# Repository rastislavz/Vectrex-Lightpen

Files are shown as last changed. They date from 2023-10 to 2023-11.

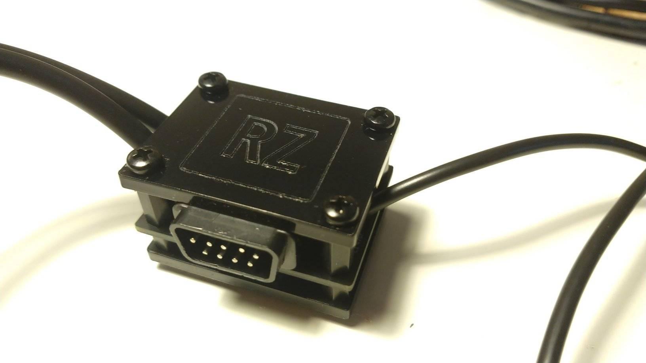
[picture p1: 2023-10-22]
Images/Lightpen2.jpg

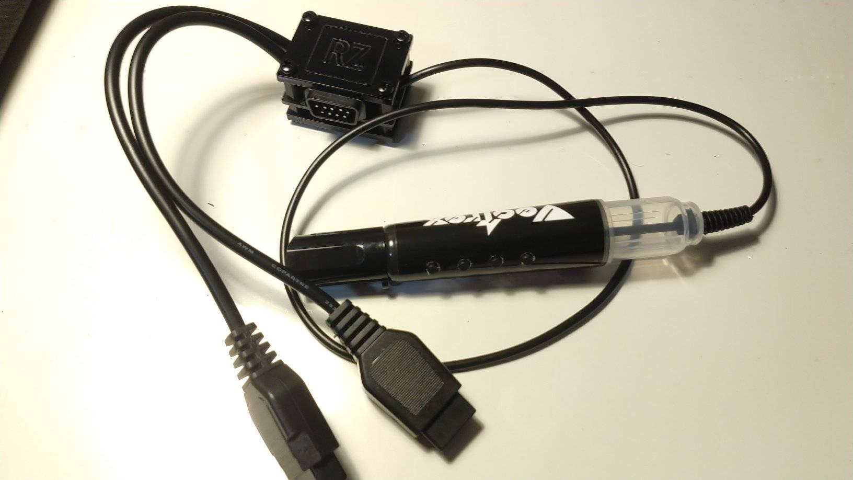
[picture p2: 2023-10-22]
Images/Lightpen1.jpg

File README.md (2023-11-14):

# Vectrex lightpen with integrated buttons

Lightpen1

# The construction details

The building of this lightpen is a bit tedious process since it uses the refillable whiteboard marker (PILOT V-Board Master 5979) instead some genuine build body.
The first step is to disembowel the marker guts: after the back is screwed open and the ink cartridge is taken out, the rest of the guts can be simply pulled out with the long nose pliers.
The next step is drilling the holes for cable and for 4 microswitch buttons. To drill the button holes precisely, i found the best way is to first apply the label with the precut button holes and to drill the holes after the label is applied. Since I had lots of labels made for the ordinary lightpen without precut holes, I have made the drill template (in svg directory) which I have printed out, overlaid with the label and than punched the holes with the leather holes puncher.

The cables are directly soldered into the PCBs. Both PCBs are designed with the holes for the cables which serves as strain relife when cables are threaded through the holes. The main body (or call it the lightpen box) PCB contains also smaller holes by which cables can be additionaly secured by cable ties.

The PCB with the microswitches and phototransistor has to be secure inside the pen with some piece of plastic/thick paper and glue.

Its quite interesting where I have found the plastic 9pin connector with 90° pins I have used in building the pen: when I needed 9pin cables for some Vectrex controllers I have used Sega etension cables and I have cut off the male part, and some of those had a small bump on it (like the one sold by console5 https://console5.com/store/atari-sega-commodore-6-1-8m-joystick-controller-extension-cable-cord.html). I was curious why that bump is there and when I have cracked it open, I have found out that Chinese have used the 90° PCB connectors for making the cable and they have just soldered wires onto the pins, but then they had to make that bump to fit. So you do not have to buy that connector if you are using the same cables for the build.

The box case is made with 2 laser cut acrilic (or whatewer material) sheet: in the svg folder.

Shield: [][cc-by-sa]

This work is licensed under a
[Creative Commons Attribution-ShareAlike 4.0 International License][cc-by-sa].

[][cc-by-sa]

[cc-by-sa]: http://creativecommons.org/licenses/by-sa/4.0/
[cc-by-sa-image]: https://licensebuttons.net/l/by-sa/4.0/88x31.png
[cc-by-sa-shield]: https://img.shields.io/badge/License-CC%20BY--SA%204.0-lightgrey.svg

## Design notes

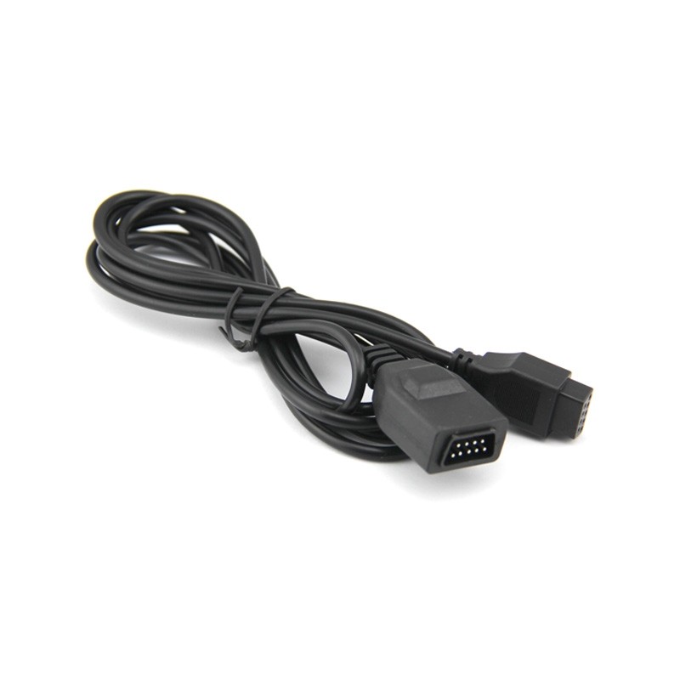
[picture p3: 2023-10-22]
Images/joystick-extension-cable.jpg

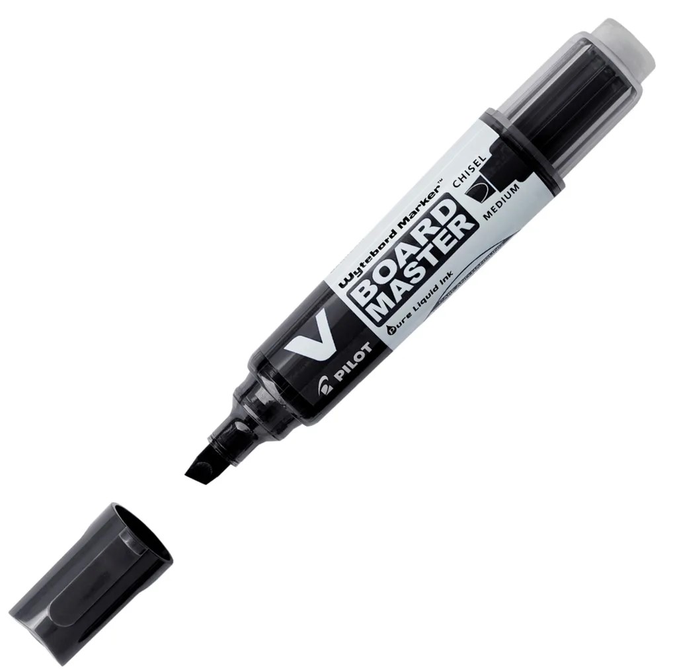
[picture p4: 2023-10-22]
Images/VBoard_marker.jpg

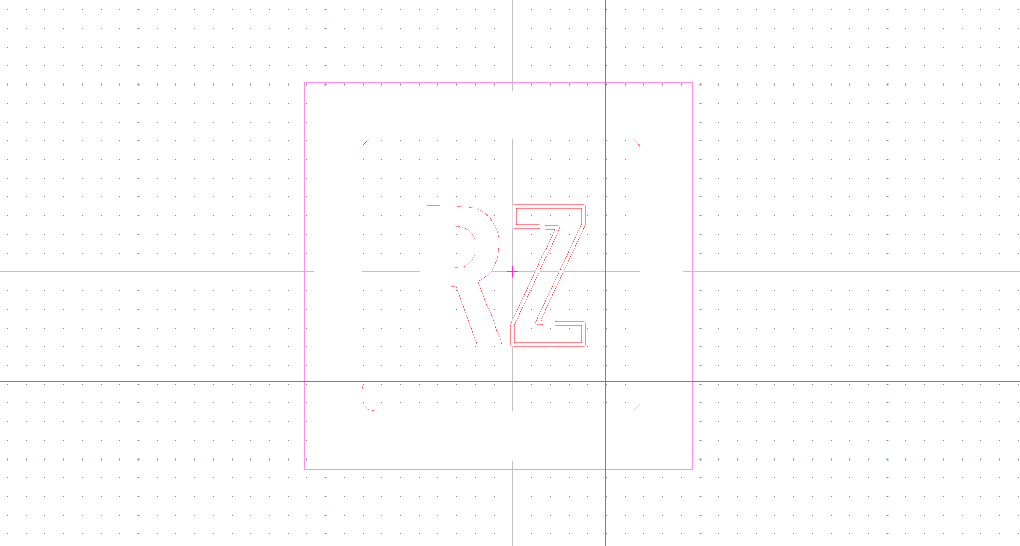
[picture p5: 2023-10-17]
KiCad/Body/RZ_10mm_inverted.png

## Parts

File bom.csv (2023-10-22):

Lightpen body
Ref | Qnt | Value | Name
R1, R2 | 2 | 10k | resistor
R3 | 1 | 2.2k | resistor
C1 | 1 | 47uF | electrolytic capacitor
C2 | 1 | 10nF | ceramic capacitor
Q1 | 1 | 2N3904 | transistor
U1 | 1 | 74LS132 | Schmitt NAND IC
 | 1 |  | Sega male connector
 | 1 |  | Body PCB
 | 2 |  | Sega 9pin cable with feemale connector
 | 3 |  | Cable tie
 | 2 |  | Acrylic sheet top/bottom
 | 4 | 6mm | M3 spacer post M+F
 | 4 | 10mm | M3 spacer post F+F
 | 4 | 5mm | M3 flat headed screw (bottom)
 | 4 | 5mm | M3 round headed screw (top)
 | 4 |  | rubber feet
Lightpen
Ref | Qnt | Value | Name
Q1 | 1 |  | phototransistor 3mm; λp max: 940nm; 30V; 30°
H1, H2, H3, H4 | 4 | 7mm | microswitch
 | 1 |  | PCB
 | 1 |  | PILOT Board 5979 marker
 | 1 | 30AWG | 6 core cable
 | 1 |  | pen label
 | 1 | 3mm | strain relief

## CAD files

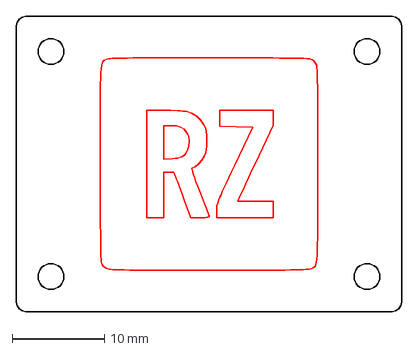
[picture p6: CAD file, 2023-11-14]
Case SVG/Vectrex_Lightpen_2.dxf
41.7 x 32.0 mm

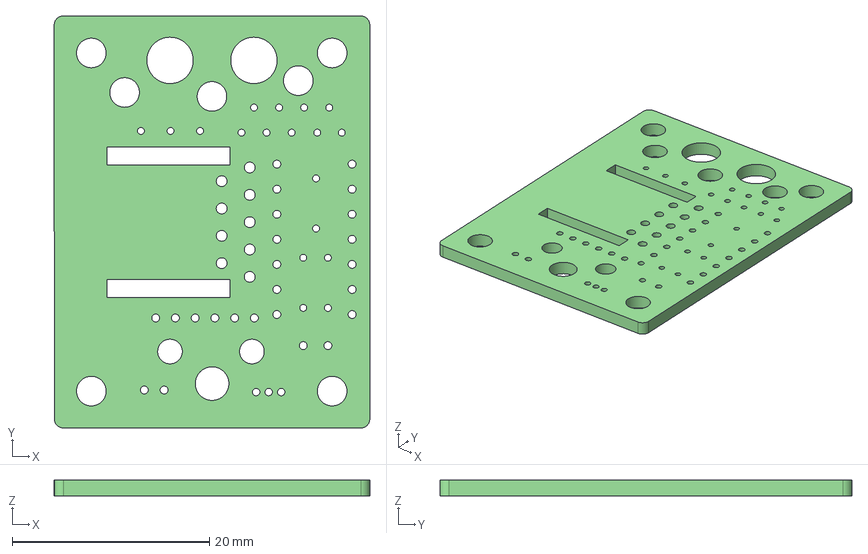
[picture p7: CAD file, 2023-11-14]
KiCad/Body/Vectrex_Lightpen_2.step
32.0 x 41.7 x 1.60 mm

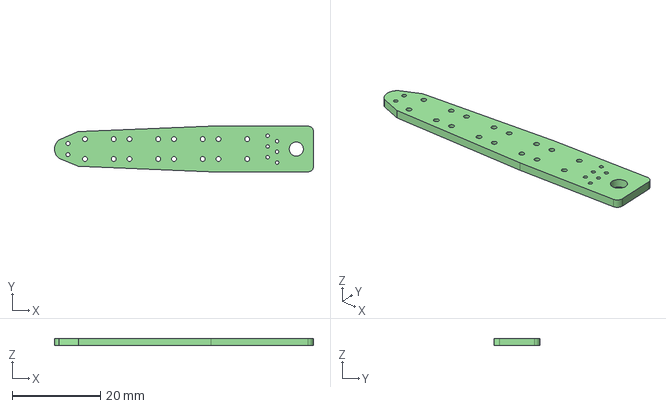
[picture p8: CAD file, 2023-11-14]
KiCad/Buttons/Vectrex_Lightpen_Buttons_2c.step
58.6 x 10.4 x 1.60 mm

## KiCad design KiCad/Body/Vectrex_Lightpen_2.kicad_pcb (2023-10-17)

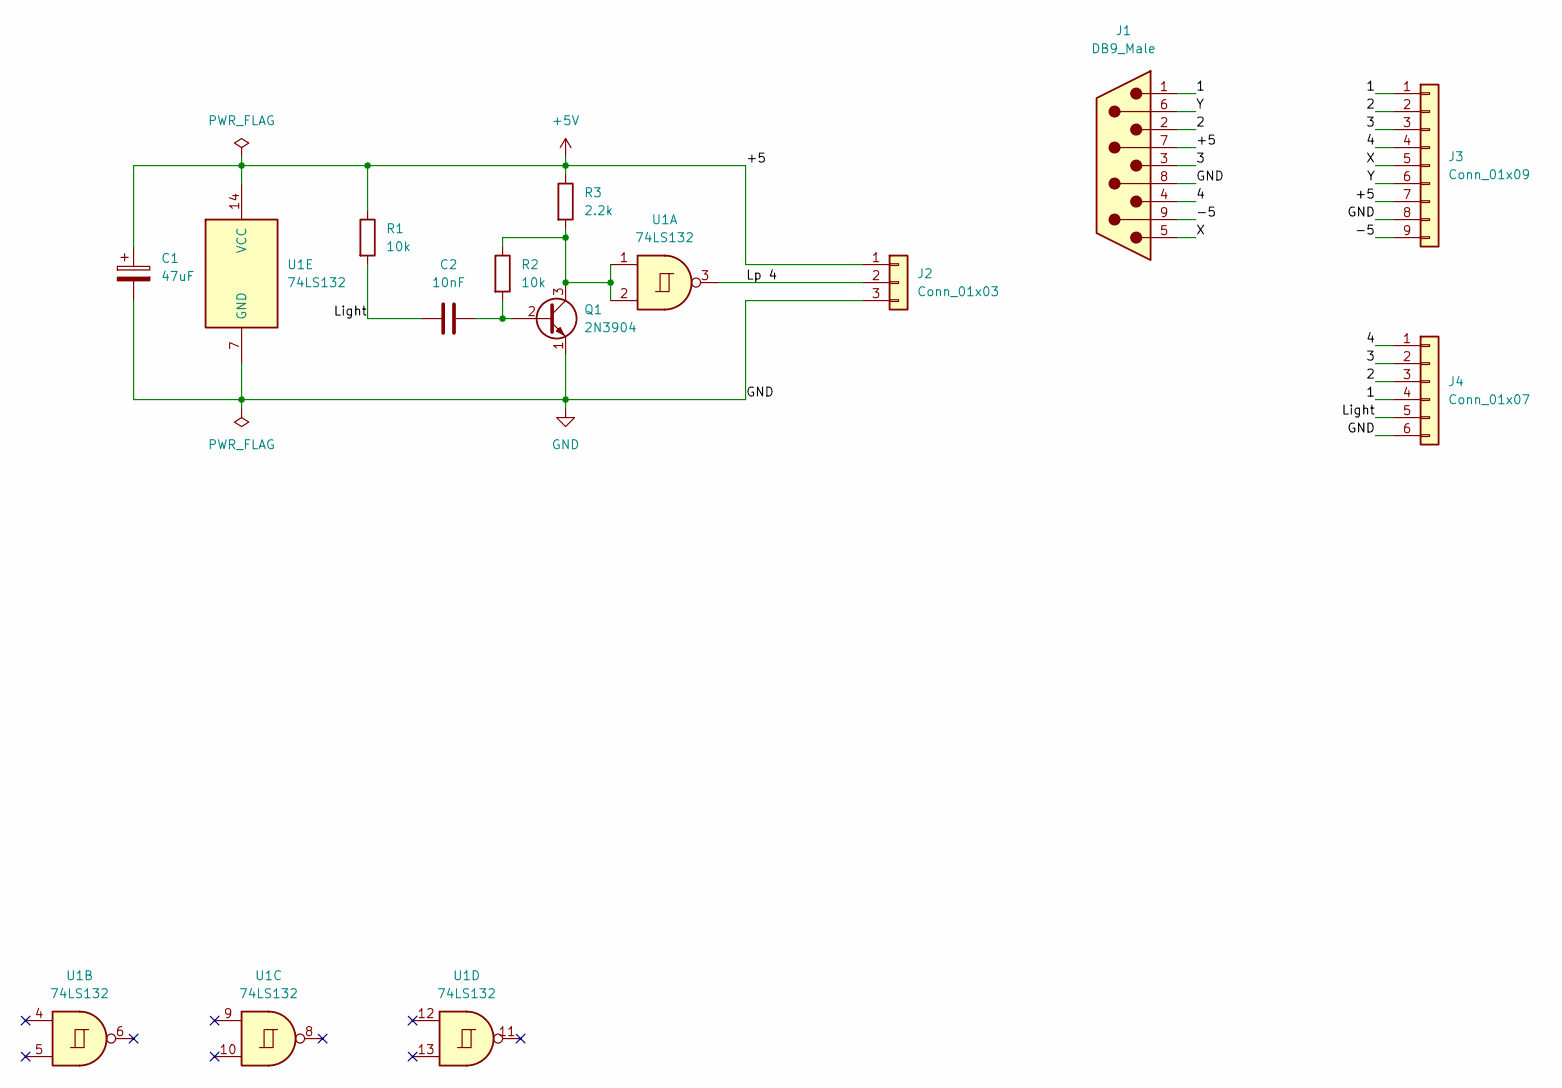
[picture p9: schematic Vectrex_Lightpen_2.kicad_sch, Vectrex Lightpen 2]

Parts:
C1: 47uF; CP_Radial_D5.0mm_P2.00mm
C2: 10nF; C_Disc_D3.0mm_W2.0mm_P2.50mm
J1: DB9_Male; DSUB-9_Male_Horizontal_Sega_Joystick
J2: Conn_01x03; SolderWire-0.1sqmm_1x03_P3mm_D0.4mm_OD1mm
J3: Conn_01x09; DSUB-9_solderwire
J4: Conn_01x07; SoldeWire_1x06_P2.00mm_Vertical
Q1: 2N3904; TO-92_Inline
R1, R2: 10k; R_Axial_DIN0204_L3.6mm_D1.6mm_P5.08mm_Horizontal
R3: 2.2k; R_Axial_DIN0204_L3.6mm_D1.6mm_P5.08mm_Horizontal
U1: 74LS132; DIP-14_W7.62mm

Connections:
+5V: C1.1, J1.7, J2.1, J3.7, R1.1, R3.1, U1.14 (VCC)
/1: J1.1, J3.1, J4.4
/2: J1.2, J3.2, J4.3
/3: J1.3, J3.3, J4.2
/4: J1.4, J3.4, J4.1
/-5: J1.9, J3.9
/Light: C2.1, J4.5, R1.2
/Lp 4: J2.2, U1.3
/X: J1.5, J3.5
/Y: J1.6, J3.6
GND: C1.2, J1.8, J2.3, J3.8, J4.6, Q1.1 (E), U1.7 (GND)
unnamed: C2.2, Q1.2 (B), R2.2
unnamed: Q1.3 (C), R2.1, R3.2, U1.1, U1.2

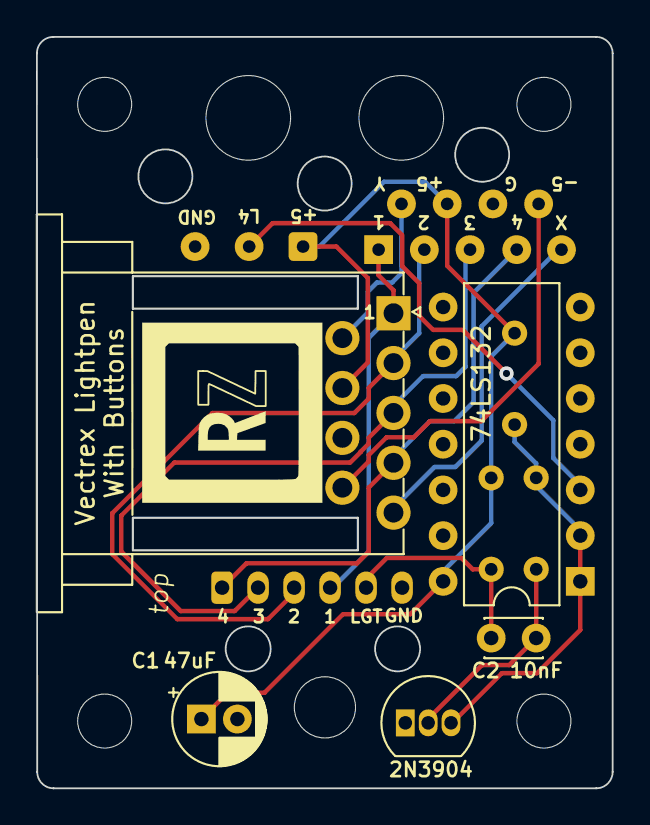
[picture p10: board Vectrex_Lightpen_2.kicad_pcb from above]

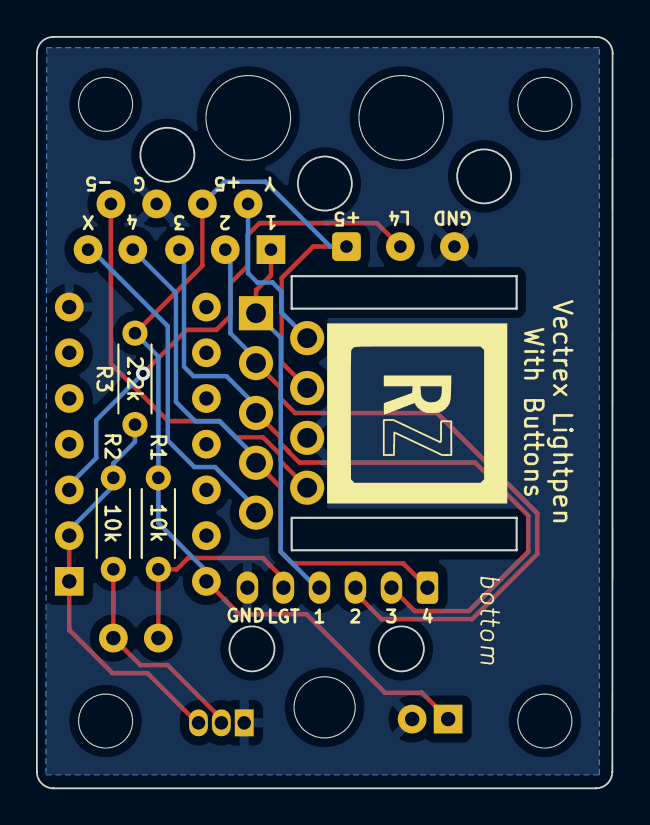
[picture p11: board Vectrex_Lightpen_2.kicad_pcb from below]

Board: 2 copper layers, 32.0 x 41.7 mm, 19 parts (4 on the bottom side), 13 nets.

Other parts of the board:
F1: LOGO; RZ_10mm_inverted
FB: LOGO; RZ_10mm_inverted
REF1, REF2, REF3, REF6: MH 2.5mm; MountingHole_2.5mm
REF5, REF7: MountingHole_4.5mm

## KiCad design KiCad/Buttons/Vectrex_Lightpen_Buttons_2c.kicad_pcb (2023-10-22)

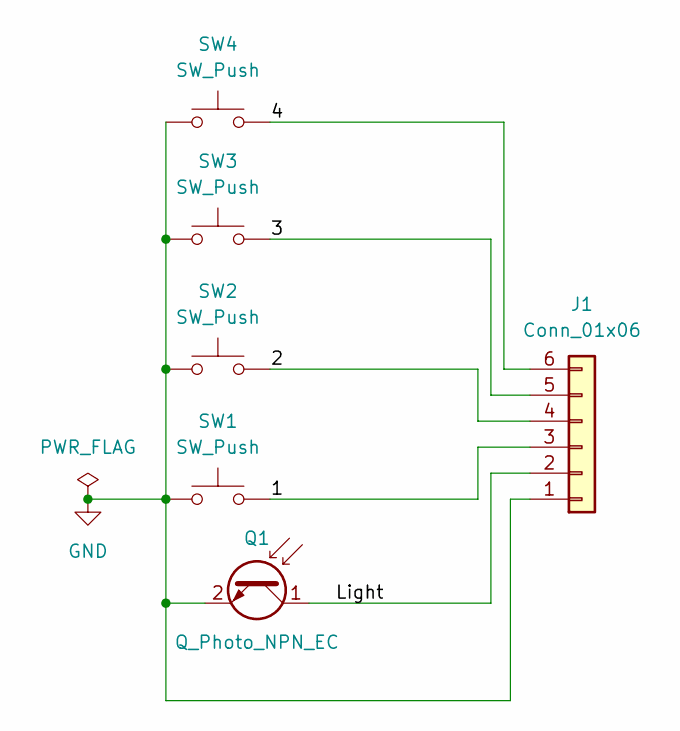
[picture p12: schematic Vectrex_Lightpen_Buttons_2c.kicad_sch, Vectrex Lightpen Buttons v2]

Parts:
J1: Conn_01x06; SoldeWire_1x06_P2.00mm_ZigZag
Q1: Q_Photo_NPN_EC; LED_D3.0mm_Clear
SW1, SW2, SW3, SW4: SW_Push; SW_PUSH_6mm_H7.3mm

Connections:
/1: J1.3, SW1.2
/2: J1.4, SW2.2
/3: J1.5, SW3.2
/4: J1.6, SW4.2
/Light: J1.2, Q1.1 (C)
GND: J1.1, Q1.2 (E), SW1.1, SW2.1, SW3.1, SW4.1

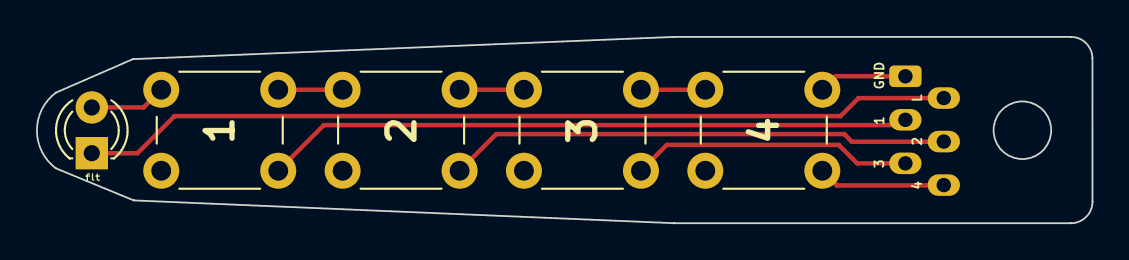
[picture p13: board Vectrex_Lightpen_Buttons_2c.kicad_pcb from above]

Board: 2 copper layers, 58.6 x 10.4 mm, 6 parts (0 on the bottom side), 6 nets.

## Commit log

2023-10-17 Renamed KiCad directory
    [Vectrex_Lightpen_2-B_Cu.gbr, Vectrex_Lightpen_2-B_Mask.gbr, Vectrex_Lightpen_2-B_Paste.gbr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]
2023-10-22 Added lightpen buttons pcb KiCad, images
    [Vectrex_Lightpen_2-B_Cu.gbr, Vectrex_Lightpen_2-B_Mask.gbr, Vectrex_Lightpen_2-B_Paste.gbr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]
2023-11-14 Export to some other file types
    [Vectrex_Lightpen_2.dxf, Vectrex_Lightpen_2.step, Vectrex_Lightpen_Buttons_2c.step]

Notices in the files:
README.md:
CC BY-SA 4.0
